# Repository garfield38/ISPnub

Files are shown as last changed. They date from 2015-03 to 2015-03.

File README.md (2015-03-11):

# ISPnub
Firmware for stand-alone AVR programmer module

Based on the work from Thomas Fischl, the v1.1 release intergrate a 1 cell Li-ion / LiPo battery connector and a 3.3 LDO regulator.

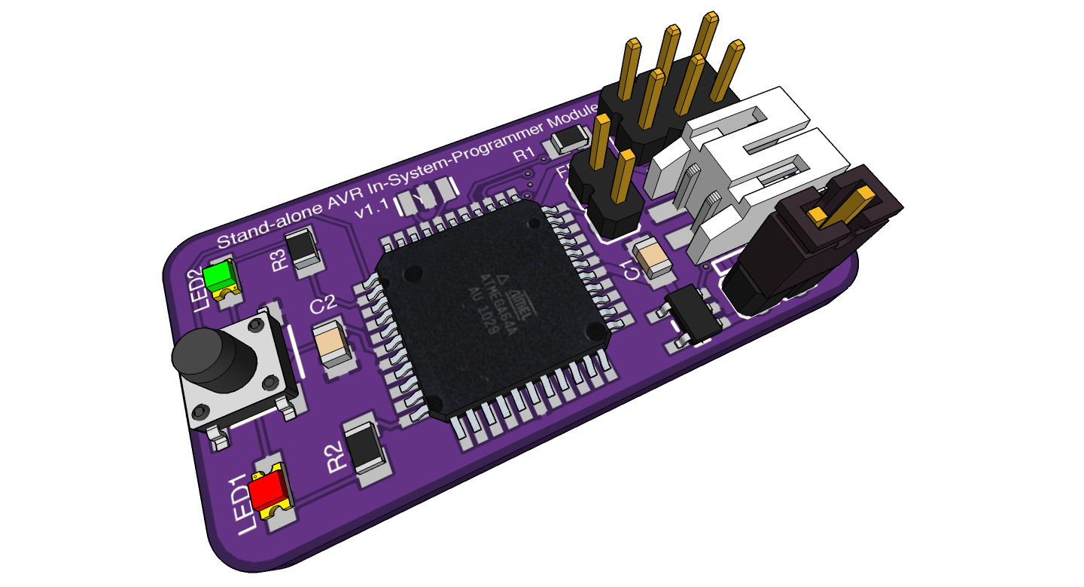
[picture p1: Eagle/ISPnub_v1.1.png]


The v1.1 release intergrate a CR2032 battery holder. Li-ion cell can be find at [Deal Extreme](http://www.dx.com/p/lir2032-rechargeable-lir2032-40mah-3-6v-lithium-cell-button-battery-silver-5-pcs-269979)

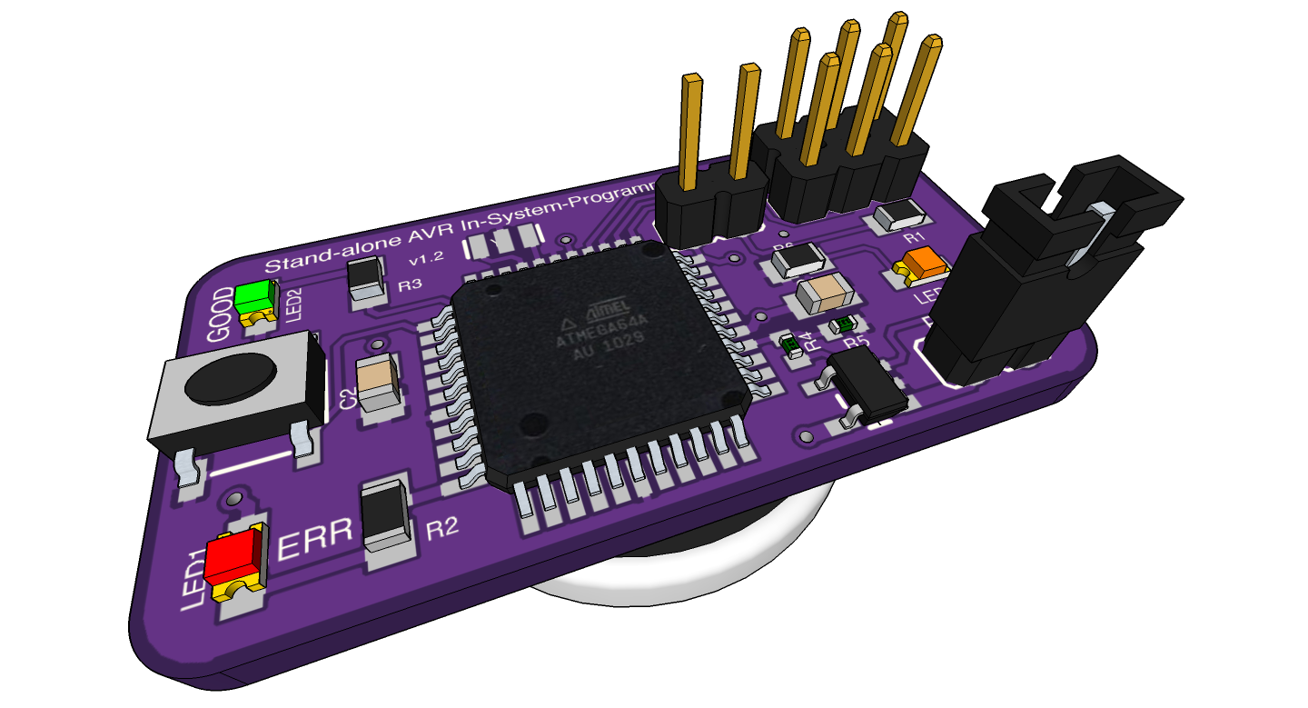
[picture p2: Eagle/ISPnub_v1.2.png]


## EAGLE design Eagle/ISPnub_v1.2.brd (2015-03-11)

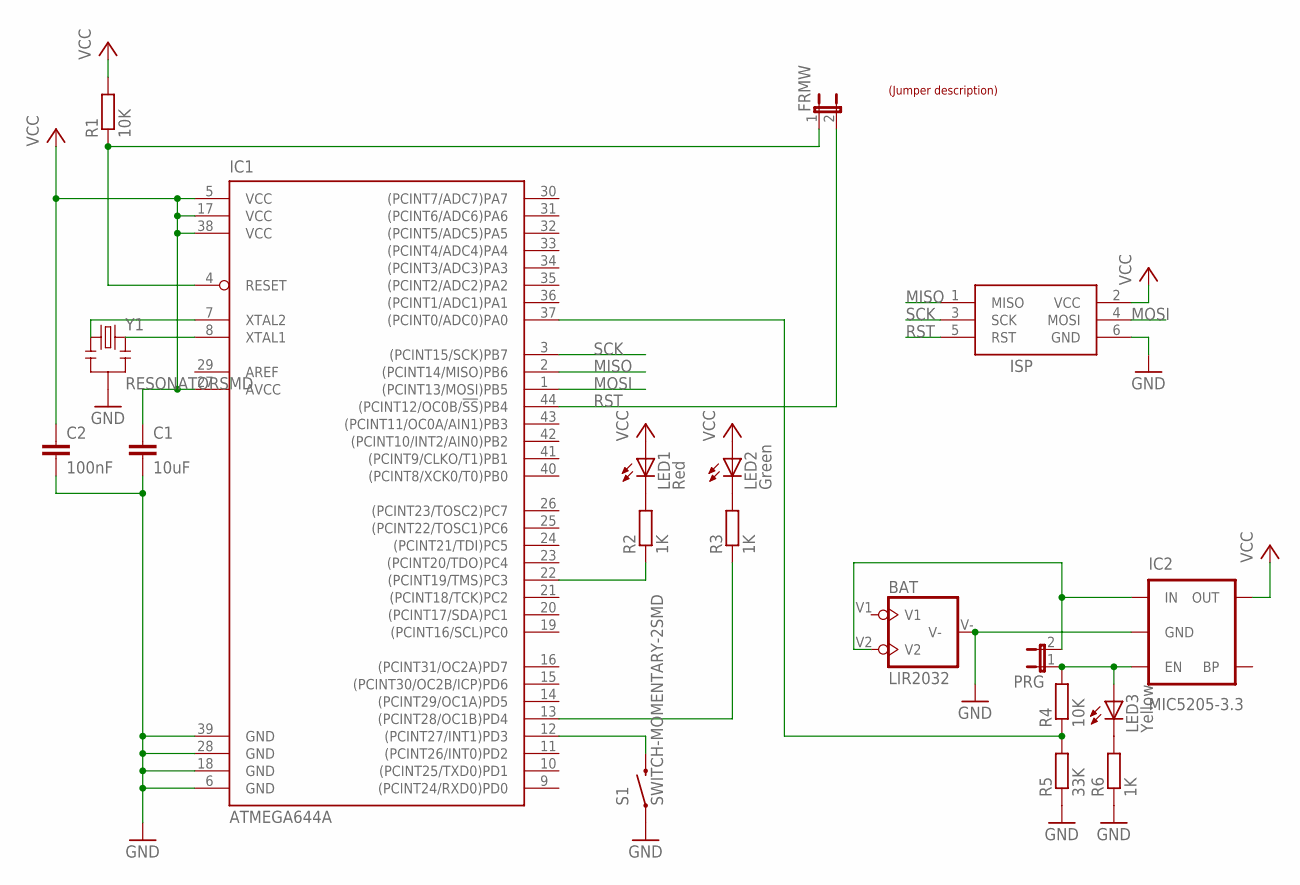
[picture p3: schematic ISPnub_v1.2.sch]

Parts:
BAT: LIR2032; BATT2032
C1: 10uF; C0805; MOUSER# 80-C0805C104K5R
C2: 100nF; C0805; MOUSER# 80-C0805C104K5R
FRMW: JP1E; JP1; MOUSER# 571-826936-2
IC1: ATMEGA644A; TQFP44; MOUSER# 556-ATMEGA1284P-AU
IC2: MIC5205-3.3; SOT23-5
ISP: AVRISP-6; AVRISP
LED1: Red; CHIP-LED0805; MOUSER# 604-APT1608SURC
LED2: Green; CHIP-LED0805; MOUSER# 604-APT2012SGC
LED3: Yellow; CHIP-LED0805; MOUSER# 604-APT1608YC
PRG: JP1E; JP1; MOUSER# 571-826936-2
R1: 10K; R0805; MOUSER# 603-SR0805JR-0710KL
R2, R3, R6: 1K; R0805; MOUSER# 71-CRCW0805-1.0K-E3
R4: 10K; R0402; MOUSER# 71-CRCW0805-1.0K-E3
R5: 33K; R0402; MOUSER# 71-CRCW0805-1.0K-E3
S1: SWITCH-MOMENTARY-2SMD; TACTILE_SWITCH_SMD; MOUSER# 693-1301.9314
U$1: LABEL_JUMPER_1X2; JUMP2_DESC
Y1: RESONATORSMD; RESONATOR-SMD

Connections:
GND: BAT.V-, C1.2, C2.2, IC1.6 (GND), IC1.18 (GND), IC1.28 (GND), IC1.39 (GND), IC2.2 (GND), ISP.6 (GND), R5.1, R6.1, S1.1, Y1.2
MISO: IC1.2 ((PCINT14/MISO)PB6), ISP.1 (MISO)
MOSI: IC1.1 ((PCINT13/MOSI)PB5), ISP.4 (MOSI)
unnamed: FRMW.1, IC1.4 (RESET), R1.1
unnamed: IC1.8 (XTAL1), Y1.3
unnamed: IC1.7 (XTAL2), Y1.1
unnamed: IC1.12 ((PCINT27/INT1)PD3), S1.3 (2)
unnamed: IC1.13 ((PCINT28/OC1B)PD4), R3.1
unnamed: LED2.C, R3.2
unnamed: IC1.22 ((PCINT19/TMS)PC3), R2.1
unnamed: LED1.C, R2.2
unnamed: BAT.V2, IC2.1 (IN), PRG.2
unnamed: IC2.3 (EN), LED3.A, PRG.1, R4.2
unnamed: IC1.37 ((PCINT0/ADC0)PA0), R4.1, R5.2
unnamed: LED3.C, R6.2
RST: FRMW.2, IC1.44 ((PCINT12/OC0B/!SS!)PB4), ISP.5 (RST)
SCK: IC1.3 ((PCINT15/SCK)PB7), ISP.3 (SCK)
V1: BAT.V1
VCC: C1.1, C2.1, IC1.5 (VCC), IC1.17 (VCC), IC1.27 (AVCC), IC1.38 (VCC), IC2.5 (OUT), ISP.2 (VCC), LED1.A, LED2.A, R1.2

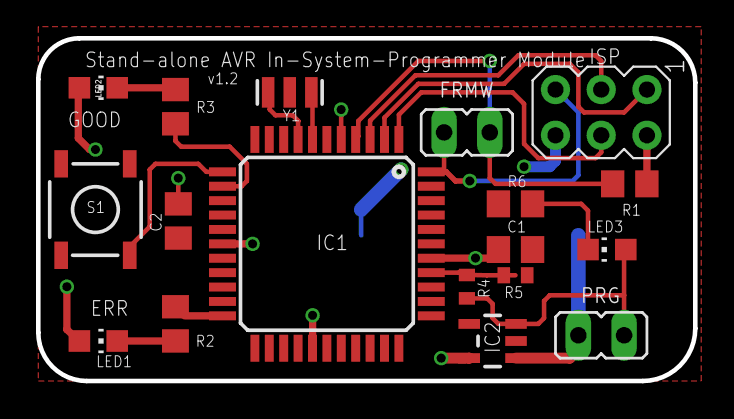
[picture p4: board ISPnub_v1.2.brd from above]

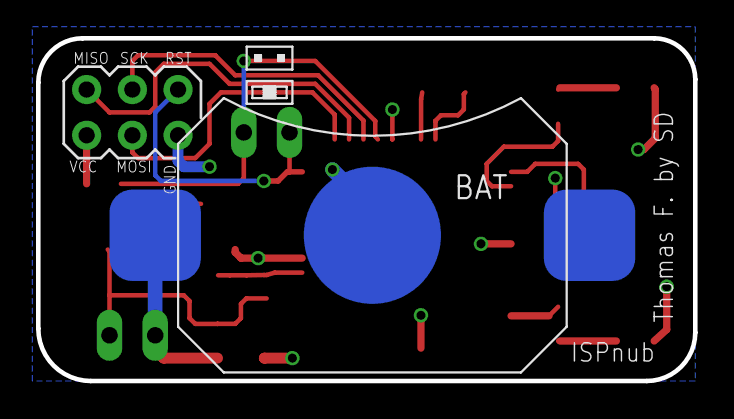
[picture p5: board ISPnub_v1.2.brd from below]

Board: 2 copper layers, 36.5 x 19.0 mm, 20 parts (2 on the bottom side), 18 nets.

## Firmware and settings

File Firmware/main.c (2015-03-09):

/**
 * @mainpage
 * ISPnub firmware project
 *
 * @section description Description
 * ISPnub is a stand-alone AVR programming module. The programming instructions
 * are defined within scripts. These scripts are converted with an additional
 * tool (ISPnubCreator) into binary information and are stored in flash. This
 * firmware interprets this binary programming instructions.
 * 
 * The firmware hex file is packed into the JAR file of ISPnubCreator which
 * merges the firmware hex data with programming instructions from scripts.
 * 
 * Environment:
 * - Target: ATmega1284P
 * - Compiler: avr-gcc (GCC) 4.7.2
 * 
 * @section history Change History
 * - v1.0 (2013-06-14)
 *   - Initial release
 * - v1.1 (2013-10-06)
 *   - Code cleanup and documentation
 * - v1.2 (2014-04-08)
 *   - Added EEPROM programming
 *
 */

/**
 * @file main.c
 *
 * @brief This file contains the main routine with application entry point for
 *        the ISPnub firmware project
 *
 * @author Thomas Fischl
 * @copyright (c) 2013-2014 Thomas Fischl
 * 
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
 */

#include <inttypes.h>
#include <avr/io.h>
#include <avr/wdt.h>
#include <avr/interrupt.h>
#include <avr/pgmspace.h>
#include "clock.h"
#include "isp.h"
#include "counter.h"
#include "hal.h"
#include "script.h"


/**
 * @brief Main routine of firmware and application entry point
 * @return Application return code
 */
int main(void) {

    hal_init();
    clock_init();

    // enable interrupts
    sei();

    uint8_t ticker = clock_getTickerSlow();
    uint8_t toggle = 0;
    uint16_t counter = counter_read();
    uint8_t success = 1;
    uint8_t keyticker = clock_getTickerSlow();
    uint8_t keylocked = 1;

    hal_setLEDgreen(1);
    hal_setLEDred(0);

    // main loop	
    while (1) {

        if (keylocked) {

            // do debouncing
            
            if (hal_getSwitch()) {
                keyticker = clock_getTickerSlow();
            } else if (clock_getTickerSlowDiff(keyticker) > CLOCK_TICKER_SLOW_500MS) {
                keylocked = 0;
            }

        } else if (hal_getSwitch()) {

            // key pressed
            
            if (counter > 0) {
                hal_setLEDgreen(1);
                hal_setLEDred(1);

                success = script_run();
                counter = counter_read();

                hal_setLEDgreen(success);
                hal_setLEDred(0);

                ticker = clock_getTickerSlow();
            } else {
                success = 0;
            }
            
            keylocked = 1;
            keyticker = clock_getTickerSlow();

        }

        // do led signaling
        if (clock_getTickerSlowDiff(ticker) > CLOCK_TICKER_SLOW_250MS) {
            ticker = clock_getTickerSlow();
            toggle = !toggle;

            if (counter == 0) hal_setLEDgreen(toggle);
            else hal_setLEDgreen(success);

            if (!success) hal_setLEDred(toggle);
            else hal_setLEDred(0);

        }
    }

    return (0);
}

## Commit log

2015-03-09 Add eagle files
    [ISPnub_v1.0.brd, ISPnub_v1.0.sch, ISPnub_v1.1.brd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]
2015-03-11 Add CR2032 Battery Holder
    [ISPnub_v1.2.brd, ISPnub_v1.2.sch]
2015-03-11 Update README.md
    Add CR2032 battery holder option

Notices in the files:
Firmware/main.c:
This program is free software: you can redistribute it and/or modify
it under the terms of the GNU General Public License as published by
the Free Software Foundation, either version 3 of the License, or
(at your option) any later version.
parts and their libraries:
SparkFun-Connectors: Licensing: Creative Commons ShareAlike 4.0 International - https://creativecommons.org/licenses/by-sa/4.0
